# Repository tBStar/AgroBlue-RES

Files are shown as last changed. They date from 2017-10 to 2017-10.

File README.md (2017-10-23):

# AgroBlue
When BLE meets agronomy.

My idea is very simple yet ambitious. Imagine a fleet of BLE enabled soil probes working in harmony that can sense the environment and be able to communicate with a central unit. This central unit will be responsible for collecting data for analysis.

This proof of concept is the understanding of how the combination of all sensors reading correlate to each other, to maximize efficiency and increase crop yield in the open. Battery longevity and cost are my main goals, let's hope it will work out.

1st Step:(PCB)
---------
- Get your board fabricated! The Eagle files are provided as-is, without warranty of any kind so use it at your own risk!
I used https://oshpark.com/ for my fabrication shop because I heard so many positive reviews. I initially opted for the regular service which takes 3 weeks but they upgraded me for free because they had free room on one of our Super Swift Service panels, So thank you OSH Park.
 - Get the components, I've included the BOM but I will list them here for the sake of having everything in one page.

|Qty|Description|URL|Price|
|---|---|---|---|
|x 1|Coin Cell Battery Holders Linx CR2032 Battery Holder|http://www.mouser.com/search/ProductDetail.aspx?r=712-BAT-HLD-001|$0.25|
|x 1|Lithium Ion Polymer Battery 3.7V 350mAh|https://www.arrow.com/en/products/2750/adafruit-industries|$6.77|
|x 2|Res Thin Film 0805 100 Ohm 1% 0.25W (1/4W)|https://www.arrow.com/en/products/rncp0805ftd100r/stackpole-electronics|$0.0052|
|x 1|Cap Ceramic 0.1uF 16V X7R 10% Pad SMD 0805|https://www.arrow.com/en/products/cl21b104koannnd/samsung-electro-mechanics|$0.02|
|x 1|Trans GP BJT NPN 40V 0.6A 3-Pin SOT-23|https://www.arrow.com/en/products/mmbt2222alt3g/on-semiconductor|$0.02|
|x 1|Lithium Battery Coin 3V 225mAh|https://www.arrow.com/en/products/cr-2032lbn/panasonic|$0.18|
|x 1|SparkFun ESP8266 Thing - Dev Board|https://www.sparkfun.com/products/13711|$15.95|
|x 1|HM-10 BLE Module|https://www.aliexpress.com/item/HM-10-cc2541-4-0-BLE-bluetooth-to-uart-transceiver-Module-Central-Peripheral-switching-iBeacon-AirLocate/32460585727.html|$3.34|
|x 1|HM-10 BLE Module Breakout Board|https://www.aliexpress.com/item/Free-shipping-HM-10-Bluetooth-BLE-4-0-Module-transparent-serial-port-Bluetooth-4-0-module/1913999168.html|$4.75|

2nd Step:(Optional if you have BLE Module Clones)
-------------------------------------------------
If you've gotten yourself some HM-10 clones, fear not. The following is an effective way to upload the original firmware to the module. We are going to be using v540. the original files can be found here: https://github.com/RedBearLab/CCLoader.

1. Load the CCLoader Arduino sketch to the UNO board.
2. Wire the pins:
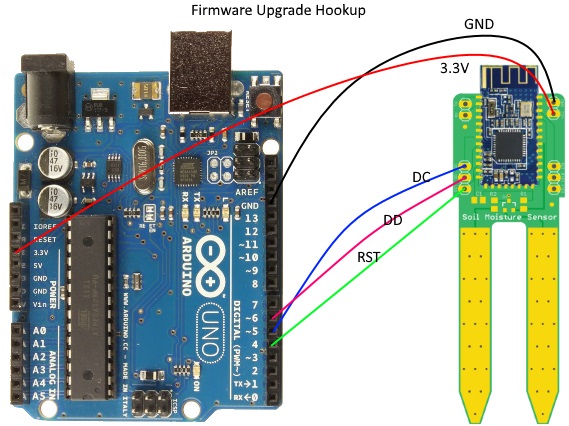
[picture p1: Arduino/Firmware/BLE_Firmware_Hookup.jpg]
  
3. Use CCLoader.exe to load the CC2541hm10v540.bin to the UNO board and the board will burn the firmware to the BLE Mini.

3rd Step: (Configure BLE Modules Master/Slave)
----------------------------------------------

a) Slave:
Upload an empty sketch to Aruidno and hookup the sensor module with it like this:

HM-10||Arduino
|---|---|---|
TX|<---->|TX
RX|<---->|RX
GND|<---->|GND
VCC|<---->|3.3V

Open the serial and type the following command to switch the mode of transmission to remote:
AT+MODE2: Remote Control Mode
AT+ROLE0: Peripheral Mode (Default)
AT+PWRM0: Auto Sleep
AT+ADVIF: Set the advertising interval to 7s (MAX)
AT+NAMEXXX: Where XXX is your preferred name
AT+BAUD4: Set the baud rate to 115200
AT+RESET: Restart module

b) Master
Hook up the BLE Module Breakout board the same way as the Sensor per below and type the following commands:

On master side:
AT+RENEW: Restore all setup value to factory setup
AT+IMME1: Only respond the AT Commands
AT+ROLE1: Central/Master Mode
AT+NAMEXXX: Where XXX is your preferred name
AT+BAUD4: Set the baud rate to 115200
AT+RESET: Restart module

c) Upgrade firmware on genuine BLE module (Optional)
AT+VERR?: Will give you the version
For example, you need to be at least at V526 for analog support.

**HM-10** is designed and made by **JNHuaMao Technology Company**
More info on the upgrading process, visit http://www.jnhuamao.cn/

4th Step: (Getting the ESP8266 Dev Ready)
-----------------------------------------
1- Make sure you hookup the BLE Central/Master with the ESP8266 per below because we will be using SoftSerial library.
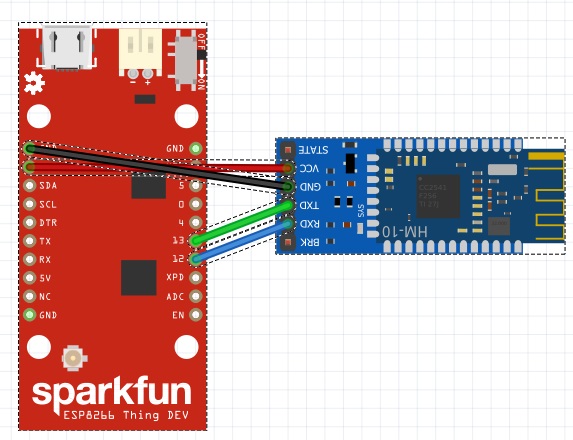
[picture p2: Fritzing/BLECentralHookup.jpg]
	
	
2- Use your Cayenne/Wifi credentials and upload main.ino located in Arduino/Code folder to the ESP8266. Open the serial and set it the baud rate to match your BLE Central.
	
3- Alternatively, you can use CentalBLEConfig.ino for debuging purposes. The code echos the serial input to the BLE and vice versa.
	
4- I found hooking up a lipo battery to the Slave BLE module works best because I found 3.3V is unusually lower for this kind of circuit. Make sure you don't hookup the cell and the lipo at the same time. There is no reverse current protection.
	
5- Water your plan and you should see some reading coming through your cloud interface through channel 0.

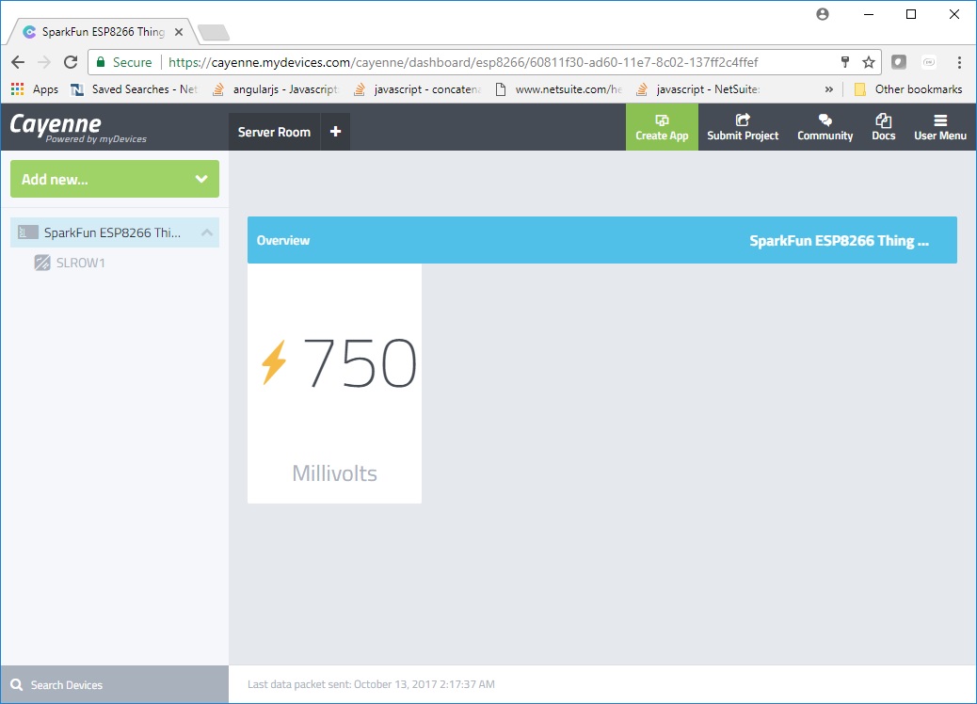
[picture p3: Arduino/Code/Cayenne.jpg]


In Summary:
-----------
I thank all the sponsors that made this contest possible. Special thanks to Sparkfun for their gratuitous dev board. I made mamy mistakes a long the way but the experience and sense of accomplishment was beyond what I imagined. I hope my work can pave the way for a continuation for finding inovative ways to improve on my design to make the world a better place.
Res stands for resistive, the probes can corrode very easily which will require replacement. As is this iteration can only be used indoor. I've done current consumption readings:
Sleep mode: 20uA
Advertising: 80uA
Connected: 8mA
Moisture Sensing: ~100mA
I found out very inefficient compared to capacitive sensing which can consume about 5mA while sensing. Very interesting indeed.

Also, to harness the full power of any BLE module is to be able to program it myself. Most of the advanced BLE modules use a flavor of ARM Cortex M processors, since they are engineered for maximum power efficiency, it makes them the rightful candidates for my next project which will be called AgroBlue-Cap.
For outdoor usage, I highly recommend you apply silicone conformal coating because the module as is can be easily damaged by environmental elements. Ideally, I would enclose the circuitry in a water/moisture proof box and use an external antenna.

Tidbits:
--------
- Sparkfun originally shipped the wrong Wifi module. They later shipped the correct one, since it was a mistake, they let me keep both.
- OshPark upgraded my order to the express service for free which costs double and take a lot less, so thank you OshPark.
- The datasheet provided by JNHuaMao Technology Company has a serious mistake. PIN3 is listed as ADC compatible while it wasn't. So bonded PIN4 to it for immediate fix, the schematics has been corrected.
- Since I was rushing to get the project out, I accidently exposed my cayenne/wifi credentials. A fatal mistake but I got a good laugh at it, so always double check and don't rush.
- I am a first timer on all levels, contest, github, eagle, board fabrication, smd soldering, youtube publishing and video recording. Quite a story there.

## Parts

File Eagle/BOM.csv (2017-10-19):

Part | Value | Device | Package | Description | PROD_ID | SF_SKU | VALUE
BT1 |  | BATTERY-20MM_SMD_4LEGS | BATTCON_20MM_4LEGS | Battery - Single Cell | BATT-10373 | PRT-11892
C1 | 0.1uf | C-EUC0805 | C0805 | CAPACITOR, European symbol
FD1 | FIDUCIAL1X2 | FIDUCIAL1X2 | FIDUCIAL-1X2 | Fiducial Alignment Points
FD2 | FIDUCIAL1X2 | FIDUCIAL1X2 | FIDUCIAL-1X2 | Fiducial Alignment Points
HM-10 | HM-10-BOARD | HM-10-BOARD | 26.9X13X2.2_BOARD | HM Bluetooth module use TI CC2540 or CC2541, Master and slave roles in one, transmission version and remote control version and PIO state acquisition functions in one, Support the AT command modify module parameters, Convenient and flexible.
IO |  | PINHD-1X3 | 1X03 | PIN HEADER
PRG |  | PINHD-1X3 | 1X03 | PIN HEADER
PWR |  | PINHD-1X2 | 1X02 | PIN HEADER
Q1 | 2N3904 | TRANSISTOR_NPNMMBT2222A | SOT23-3 | Generic NPN BJT | TRANS-08049 |  | MMBT2222A
R1 | 100 | 100OHM-1/4W-5%(0603) | 0603-RES |  | RES-12438 |  | 100/.25W
R2 | 100 | 100OHM-1/4W-5%(0603) | 0603-RES |  | RES-12438 |  | 100/.25W
UART |  | PINHD-1X2 | 1X02 | PIN HEADER

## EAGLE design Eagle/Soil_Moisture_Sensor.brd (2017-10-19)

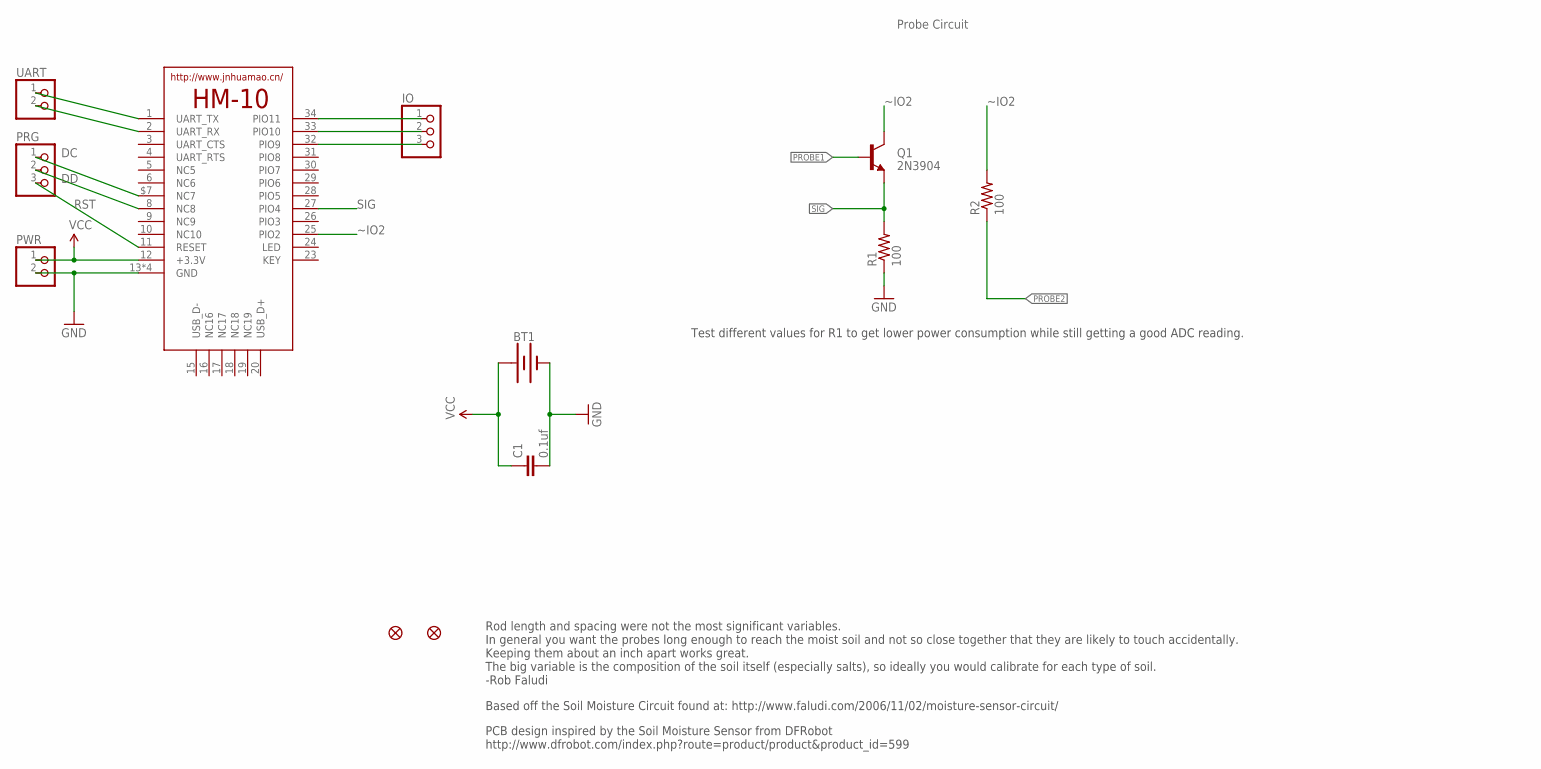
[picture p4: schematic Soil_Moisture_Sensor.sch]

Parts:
BT1: BATTERY-20MM_SMD_4LEGS; BATTCON_20MM_4LEGS
C1: 0.1uf; C0805
FD1, FD2: FIDUCIAL1X2; FIDUCIAL-1X2
HM-10: HM-10-BOARD; 26.9X13X2.2_BOARD
IO: PINHD-1X3; 1X03
PRG: PINHD-1X3; 1X03
PWR: PINHD-1X2; 1X02
Q1: 2N3904; SOT23-3
R1, R2: 100; R0805
UART: PINHD-1X2; 1X02

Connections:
DC: HM-10.$7 (NC7), PRG.1
DD: HM-10.8 (NC8), PRG.2
GND: BT1.NEGATIVE (-), C1.2, HM-10.13 (GND), HM-10.14 (GND), HM-10.21 (GND), HM-10.22 (GND), PWR.2, R1.1
unnamed: HM-10.34 (PIO11), IO.1
unnamed: HM-10.33 (PIO10), IO.2
unnamed: HM-10.32 (PIO9), IO.3
unnamed: HM-10.1 (UART_TX), UART.1
unnamed: HM-10.2 (UART_RX), UART.2
PROBE1: Q1.1 (B)
PROBE2: R2.1
RST: HM-10.11 (RESET), PRG.3
SIG: HM-10.27 (PIO4), Q1.2 (E), R1.2
VCC: BT1.POSITIVE@1 (+), BT1.POSITIVE@2 (+), BT1.POSITIVE@3 (+), BT1.POSITIVE@4 (+), C1.1, HM-10.12 (+3.3V), PWR.1
~IO2: HM-10.25 (PIO2), Q1.3 (C), R2.2

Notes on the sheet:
Test different values for R1 to get lower power consumption while still getting a good ADC reading.
Based off the Soil Moisture Circuit found at: http://www.faludi.com/2006/11/02/moisture-sensor-circuit/
Rod length and spacing were not the most significant variables. In general you want the probes long enough to reach the moist soil and not so close together that they are likely to touch accidentally. Keeping them about an inch apart works great. The big variable is the composition of the soil itse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
Probe Circuit
PCB design inspired by the Soil Moisture Sensor from DFRobot http://www.dfrobot.com/index.php?route=product/product&product_id=599

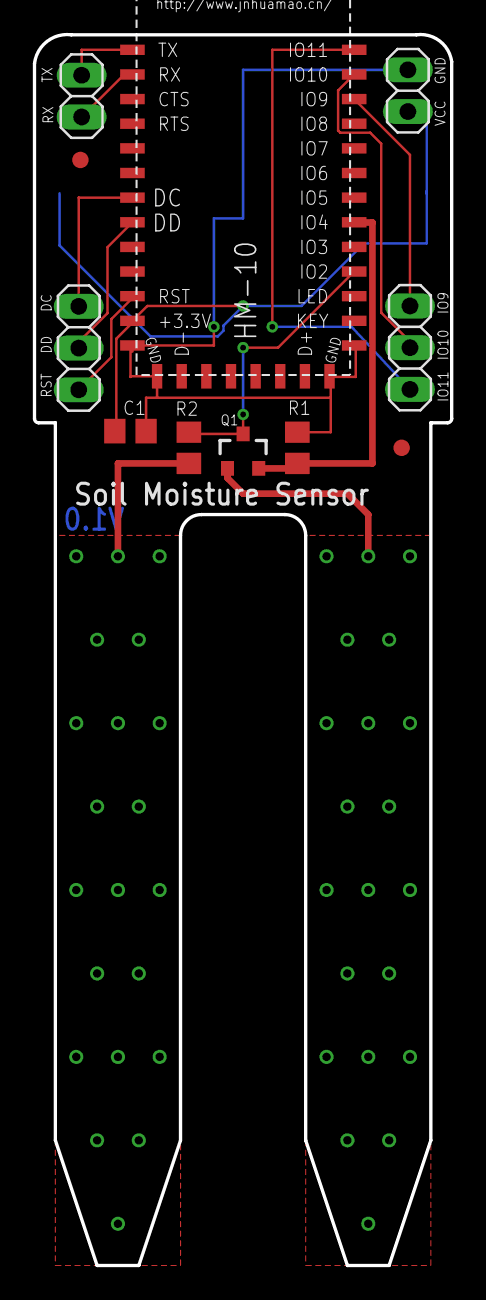
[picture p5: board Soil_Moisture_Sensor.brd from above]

Board: 2 copper layers, 25.4 x 74.9 mm, 12 parts (1 on the bottom side), 12 nets.

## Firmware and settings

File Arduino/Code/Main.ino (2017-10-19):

#include <CayenneMQTTESP8266.h>
#include <SoftwareSerial.h>


// WiFi network info.
char ssid[] = "xxxxxxx";
char wifiPassword[] = "xxxxxx";

// Cayenne authentication info. This should be obtained from the Cayenne Dashboard.
char username[] = "xxxxx";
char password[] = "xxxxx";
char clientID[] = "xxxxx";

SoftwareSerial BLE(13, 12); // RX, TX  
							// Connect HM10      Arduino Uno
							//     Pin 1/TXD          Pin 13
							//     Pin 2/RXD          Pin 12
bool bleFound = false;
byte outerCounter = 0;
byte innerCounter = 0;

void setup() {
	Serial.begin(115200);
	// If the baudrate of the HM-10 module has been updated,
	// you may need to change 9600 by another value
	// Once you have found the correct baudrate,
	// you can update it using AT+BAUDx command 
	// e.g. AT+BAUD0 for 9600 bauds
	BLE.begin(115200);
	//delay(250);
	//String serialResponse = "";

	//BLE.print("AT");
	//delay(250);
	//if (BLE.available())
	//{
	//	serialResponse = BLE.readStringUntil('\r\n');
	//	Serial.println(serialResponse);
	//}

	//Connect to the WiFi and establish Cayenne cloud session
	Cayenne.begin(username, password, clientID, ssid, wifiPassword);
}

void loop() {
	char *buffer;
	char data[100];
	Cayenne.loop(1000);

	Serial.println("OuterLoop: " + String(outerCounter));

	if (!bleFound)
	{
		BLE.print("AT+DISC?");
		delay(2000);
	}

	int dataCount = BLE.available();
	if (dataCount > 0)
	{
		//Get data from UART stream
		BLE.readBytesUntil('\r\n', data, dataCount);
		data[dataCount + 1] = '\0';
		buffer = strstr(data, "NAME:");
		if (buffer)
		{
			Serial.println("InnerLoop: " + String(innerCounter));
			innerCounter++;
			bleFound = true;
			//int nameLength = strlen(buffer - 5);
			char slaveName[13];
			char slaveAddress[13];

			strcpy(slaveName, buffer + 5);
			slaveName[12] = '\0';
			Serial.println(String(slaveName));

			buffer = strstr(data, "DIS0:");
			strncpy(slaveAddress, buffer + 5, 12);
			slaveAddress[12] = '\0';
			Serial.println(String(slaveAddress));

			BLE.print("AT+CON" + String(slaveAddress));
			delay(1000);
			Serial.println(BLE.readStringUntil('\r\n'));
			BLE.print("AT+PIO21");
			delay(1000);
			Serial.println(BLE.readStringUntil('\r\n'));
			BLE.print("AT+ADC4?");
			delay(1000);
			String hum = BLE.readStringUntil('\r\n');
			Serial.println(hum);
			long humidity = hum.substring(8).toFloat() * 1000;
			Serial.println(hum.substring(8).toFloat());
			//byte humidity = hum.substring(8).toFloat() * 100;
			BLE.print("AT");
			Cayenne.virtualWrite(0, humidity,TYPE_VOLTAGE, UNIT_MILLIVOLTS);
		}
		else
			bleFound = false;
	}
	else
		bleFound = false;

	delay(10000);
	outerCounter++;
	memset(data, 0, sizeof(data));
}

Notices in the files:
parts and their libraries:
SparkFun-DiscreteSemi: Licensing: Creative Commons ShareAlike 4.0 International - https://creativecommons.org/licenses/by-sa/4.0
